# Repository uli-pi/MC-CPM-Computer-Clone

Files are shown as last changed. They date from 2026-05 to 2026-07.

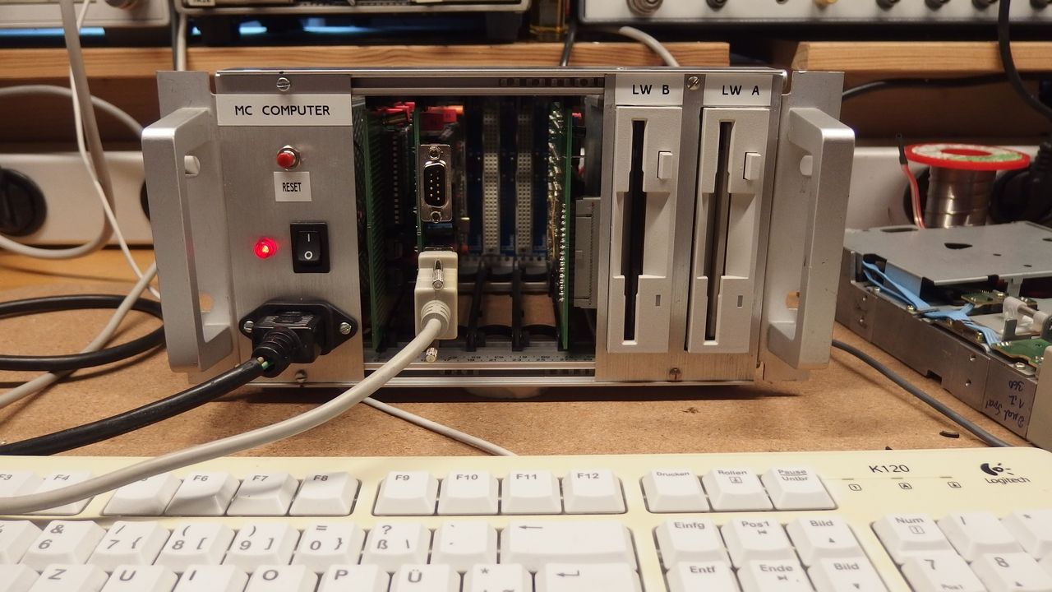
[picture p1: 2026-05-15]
MC-CLONE.jpg

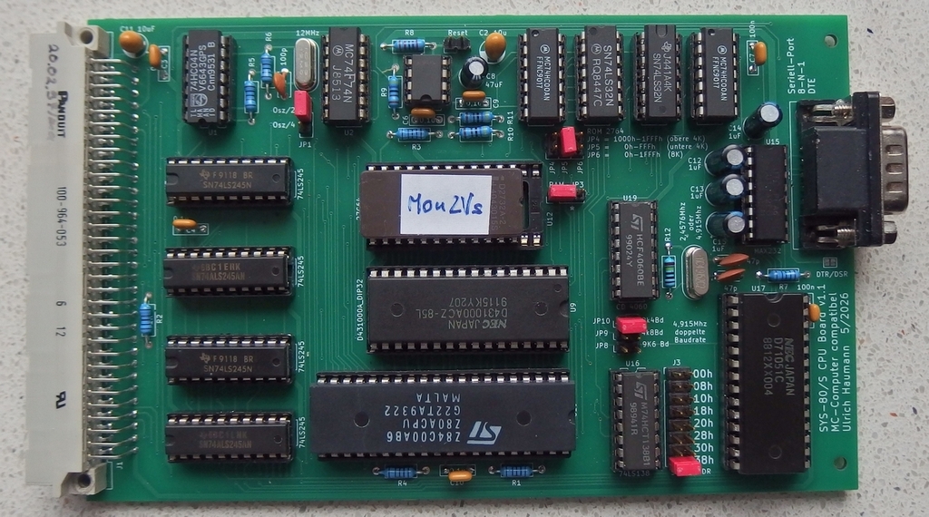
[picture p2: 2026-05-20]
SYS-80s/SYS-80s-V1.1.jpg

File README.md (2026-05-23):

# MC-Computer CP/M Computer Clone
 
Hier entsteht ein MC CP/M Computer kompatibler Rechner. Dieser wurde in der Zeitschrift MC Computer 1984 als Nachbauprojekt veröffentlicht. Der Autor war Rolf-Dieter Klein der auch den NDR Computer gleichzeitig entwickelte.
Das Projekt ist als "Retro" Computing Projekt ausgelegt. Die Karten werden nicht 1:1 "gecloned" sondern mit einigen Verbesserungen neu aufgelegt. Es wird aber alles weitgehend mit Chips aus der Zeit aufgebaut werden, also kommen keine SMD Bauteile oder Microcontroller wie Raspi, Arduino oder ähnliches zum Einsatz.

Es werden nachfolgend die Baugruppen CPU Karte (SYS-80s), OUT Karte (OUT-80), Floppy Controller (FLO-80), sowie einige neue Karten hier veröffentlicht. Die Karten sind ECB Bus Kompatibel zu eventuell vorhandenen Karten aus den 80ziger Jahren. Diese können gemischt betrieben werden. Wer also noch einen MC-CPM Computer sein eigen nennt kann z.B. Die CPU Karte gegen die neue SYS-80s tauschen usw.

Die CF Karte ermöglicht den Anschluß eines IDE Kompatiblen Gerätes. Es lassen sich Festplatten, oder auch mit Adapter eine CF Karte ansteuern. Mit dem CF Karten Bios werden 4 Floppy Disk mit jeweils 2MB Kapazität nachgebildet.

Ein minimales CP/M 2.2 System kann mit einer SYS-80s und einer CF-80 Karte aufgebaut werden. Man hat einen vollwertigen Rechner mit einem 60KB CP/M. Oder sie nehmen eine SYS-80s mit einer FLO-80 Karte. Das ergibt einen CP/M Rechner mit richtigen Floppy Laufwerken. Anschluß von 3,5", 5,25" oder 8" ist möglich, auch gemischt je nach Bios.

Mit einer OUT-80 Karte bekommt man zusätzlich 2 serielle und 2 parallele Schnittstellen.

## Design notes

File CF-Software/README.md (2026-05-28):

# CF-80 Karte - CP/M Install Anleitung für eine CF Speicherkarte

CF-Menue

Die Karte wurde für das MC-Computer ECB Bus System entwickelt und verwendet nur 8 Bit des angeschlossenen 16Bit Mediums. Das halbiert schon einmal vorweg die nutzbare Kapazität. Es sollte ein Datenträger mit mindestens 128MB verwendet werden.
Es kann auch eine ATA  oder eine SSD Festplatte verwendet werden. Das Format Programm erstellt 4 Laufwerke (LW A bis D) mit jeweils 2MB Speicherkapazität.
 
Anschluss eines Laufwerks:

Diese Karte funktioniert mit den meisten IDE/CF/SSD-Laufwerken. Die Kapazität des Laufwerks sollte 128 Megabyte oder mehr betragen, wenn Sie CP/M installieren möchten. Dies ist nicht erforderlich, um genügend Speicherplatz zu haben – denn ein vollwertiges CP/M-System belegt unter 1 MB an Speicherplatz –, sondern vielmehr weil die von mir verwendeten Treiber vereinfachten Code verwenden, der den Speicherplatz nicht sehr effizient nutzt. Es kommt eine vereinfachte Arithmetik zum Einsatz, um die CP/M-Sektoren auf die LBA-Sektoren der Festplatte abzubilden. Dabei bleibt ein erheblicher Teil des Speicherplatzes ungenutzt.  Es kann aber jeder einen Treiber selbst für das System schreiben um den Speicherplatz auszunutzen. 
Viele kleine Solid-State-Flash-Module benötigen keinen separaten Stromanschluss; stattdessen können Sie die +5V-Spannung (bei geringer Stromaufnahme) direkt über Pin 20 des Laufwerksanschlusses beziehen. Bei der vorliegenden Karte liegt dieser auf +5V und die SSD bzw. CF Karten benötigen daher keine externe Spannungsversorgung.

Die Adressen sind auf der Karte zwischen 010h bis 078h einstellbar, es werden 8 Adressen benutzt.
Für das SYS-80 System liegt die Basis Adresse auf 018Hex.

Adressen IDE Port CF-80 Karte

	IDEDATA	EQU 0x8h			;IDE Daten Register
	SECCND	EQU 0xah			;Sector Count Register
	LBA7	EQU 0xbh			;LBA Bits 0-7
	LBA15	EQU 0xch			;LBA Bits 8-15
	LBA23	EQU 0xdh			;LBA Bits 16-23
	IDEHEAD	EQU 0xeh			;IDE Drive Head Register
	IDESTAT	EQU 0xfh			;IDE Command/Status Register

Wie bekommt man nun CPM auf den Datenträger ?
Voraussetzung ist die MC-Computer SYS-80  Systemkarte mit Monitor Eprom  für den IDE-80 CF-Adapter.
Zum Erstellen einer CP/M bootfähigen CF-Karte bedienen wir uns des Monitor der SYS-80 Karte. Dieser beinhaltet viele Kommandos die zum Aufsetzen und testen eines Systems hilfreich sind.
Folgende Monitor Kommandos werden benötigt:

R offset	lädt ein INTEL HEX File über die Terminal Schnittstelle in das RAM

G offset	springt an die angegebene Adresse und  startet das Programm

Alle Monitorbefehle sind im original SYS-1 Handbuch zu finden.

Wir brauchen ein Terminalprogramm das Binärfiles über die Serielle Schnittstelle zur Console  senden kann. Ich benutze dazu RealTerm.
Die Speicheraufteilung des MC-Systems ist wie folgt:

F000 Hex ab dieser Adresse beginnt der Monitorbereich bis FFFF Hex

EA00 HEX ist die Ladeadresse des BIOS

D400 HEX ist die Ladeadresse des CCP/BDOS
	 
Daraus geht hervor wohin wir die Binärfiles laden müssen.
 
Nachfolgende Binärfiles im INTEL HEX Format werden benötigt. Sie befinden sich mit den Sourcen im CF-Software Verzeichnis.

CBIOS-CF.HEX		das angepasste Bios für die CF-Karte (Adresse EA00h)

CPM22.HEX			CCP und BDOS, original von DR (Adresse D400h)

FORM-CF.HEX		Formatiert 4 Laufwerke (Adresse 8000h)

PUTSY-CF.HEX		Kopiert CP/M auf Systemspuren (Adresse 8000h)

BLOAD-CF.HEX		Bootloader (Adresse 8000h)

BOOT-CF.HEX		Schreibt Bootloader auf LBA0 (Adresse 100h)

System Starten, Monitor meldet sich mit  > Prompt.

Um das System in einen definierten Ausganszustand zu bringen leert man zuerst den  Speicher mit folgendem Monitor Befehl  f0,ef00,0  ->Enter. 

Es muss der Datenträger für das CPM vorbereitet (formatiert) werden. Dazu nutzten wir das CPM Bios das auf den Datenträger soll. Es beinhaltet alle Funktionen die zum Schreiben von Sektoren im richtigen Format nötig sind.

Der Monitor kann nur Dateien im INTEL HEX Format empfangen!

Im Monitor eingeben rea00  -> Enter, der Monitor erwartet jetzt eine Datei die er auf Adresse EA00 Hex abspeichert.

Nun wird in Real Term mit der Send Funktion die Datei CBIOS-CF.Hex übertragen. Ist die Übertragung korrekt erfolgt meldet sich der Monitor mit FF* wieder zurück.

Nach der gleichen Methode  wird nun FORM-CF.HEX auf Adresse 8000h geladen (r8000 -> Enter).

Dann startet man das Formatprogramm mit g8000 -> Enter

Jetzt sollte das Formatprogramm arbeiten. Es werden 4 Laufwerke formatiert und die „Disk Aktiv“ LED auf der Karte leuchtet.
Das Programm  zeigt den Formatierungsfortschritt an. Geduld, das dauert ein paar Minuten. Das Programm springt, wenn fertig, wieder in den Monitor zurück.
Wenn der  Datenträger formatiert ist kann CP/M aufgespielt werden.

Die erste Datei ist CPM22.HEX, Diese kommt auf Adresse D400h. Das geht wieder  mit dem R Kommando:  rd400 -> Enter. Diese originale DR Datei enthält das CCP, BDOS und eine leere Sprungtabelle für CP/M 2.2. Datei in Real Term auswählen und übertragen.

Dann patchen wir das BIOS in das leere CP/M. Dies ist die Datei CBIOS-CF.HEX, kommt auf Adresse EA00h. Wie gehabt mit dem R Befehl (rea00 -> Enter).

Das komplette CP/M ist nun im Ram und muss auf den Datenträger geschrieben werden.
Dazu lädt man nun PUTSY-CF.HEX auf Adresse 8000h 

Mit einem G Befehl auf Adresse 8000h (g8000 -> Enter) wird das Programm gestartet und schreibt CP/M auf den Datenträger. Nun sollte die LED auf der CF-80 Karte kurz aufleuchten.

Im Übrigen ist CP/M jetzt betriebsbereit wir haben nur noch keinen Kalt Start (BOOT).
Geben Sie gea00 -> ein und CP/M wird sich melden.

Zum Weitermachen wieder in den Monitor mit dem Reset Knopf.

Jetzt fehlt nur noch der „Cold Boot Loader“ um CP/M bei einem Kaltstart ins Ram zu schreiben und zu starten.
Dazu wird BLOAD-CF.HEX auf Adresse 8000h geladen.

Danach wird BOOT-CF.HEX auf Adresse 100h geladen (r100 )und mit g100 gestartet.

Reset Knopf drücken. Nun wird mit dem Monitor Befehl  I  das Bootmenue aufgerufen und mit Auswahl =2 die CF Karte ausgewählt. Das CP/M sollte starten.

Wir haben ein CP/M mit 4 Laufwerken (A bis D) und keine Dateien auf dem Datenträger. Das macht keinen Spaß, wir brauchen Programme.

Dazu benutzen wir erst einmal wieder unsere Lademethode mit Monitor und RealTerm. Reset drücken, wir brauchen den Monitor.

Die Datei der Begierde ist GETPC.COM , damit lassen sich alle Dateien über XMODEM auf unser CP/M laden.
Mit r100h, GETPC.HEX ins RAM laden. 

Nun wird mit dem Monitor Befehl  I  das Bootmenue aufgerufen und mit Auswahl =2 die CF Karte ausgewählt. Das CP/M sollte starten. 
Das GETPC ist immer noch unversehrt im RAM.

Das erste Kommando in CP/M ist nun save 5 getpc.com und wir haben das Programm auf dem Datenträger. Somit lassen sich beliebige Programme auf den Datenträger überspielen was aber ziemlich mühsam wäre. Aber wir haben jetzt GETPC.

Wir wechseln das Terminal Programm und verwenden ab sofort TerraTerm. Dieses Programm hat ein integriertes XMODEM.

Auf auf dem CP/M Rechner rufen wir GETPC Filename.ext auf. Filename.ext entspricht der Datei die wir übertragen wollen. Dann wartet CP/M auf das File. Der Filename ist frei wählbar das Programm überträgt einfach die Datei und speichert sie unter dem gewählten Namen ab.

Auf dem PC im Programm TerraTerm sind es die Kommandos DATEI, TRANSFER, XMODEM, SEND und Datei auswählen. Wir brauchen uns über Länge und Speicherplatz nicht mehr zu kümmern. Das machen die Programme untereinander aus.

Zurückspielen von CP/M auf PC geht dann mit PCPUT.com das wir ja jetzt mit GETPC  einfach auf unseren CP/M Rechner holen können.
GETPC.com und PUTPC.com sind Kopien von PCGET.com und PCPUT.com die auf die Hardware der SYS80s Karte angepasst wurden. Ich habe diese umbenannt damit man nicht mit den Varianten für das originale System mit OUT Karte durcheinander kommt. Da die Programme direkt über die Hardware kommunizieren, müssen sie immer an die verwendete Hardware angepasst werden.

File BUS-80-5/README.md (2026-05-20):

# 5-Slot-Backplane

Backplane mit 5 Slots zur direkten Montage in Baugruppenträger oder in das unten verlinkte Gehäuse ohne Z-Schiene.

BUS-80-5

JLCPCB-geprüfte Gerber-Files im Verzeichnise /gerber

Achtung - Dies ist eine Kopie des 8-Slot-Busboards, wobei im Layout-Editor 3 Slot entfernt wurden ohne den Schaltplan anzupassen.

Passendes Gehäuse bei Reichelt Elektronik: https://www.reichelt.de/de/de/shop/produkt/systemgehaeuse-50437

Erstellt mit KiCAD 9.07 / Detlef Gerhardt

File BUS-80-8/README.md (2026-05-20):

# 8-Slot-Backplane

Backplane mit 8 Slots zur direkten Montage in Baugruppenträger oder in das unten verlinkte Gehäuse ohne Z-Schiene.

BUS-80-8

Passendes Gehäuse bei Reichelt Elektronik: https://www.reichelt.de/de/de/shop/produkt/systemgehaeuse-50437

Erstellt mit KiCAD 9.07 / Detlef Gerhardt

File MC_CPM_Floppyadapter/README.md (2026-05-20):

# 3 1/2" Floppy-Adapter

Adapter zum Anschließen von 3 1/2" PC-Laufwerken an den Floppy-Controller des MC-CPM-Clones.
Dabei werden die 4 Drive-Select-Leitungen vom Controller in die MOTOR_ON A/B und DRIVE SELECT A/B Leitungen des Laufwerks angepasst.

Adapter1

JLCPCB-geprüfte Gerber-Files im Verzeichnise /gerber

Erstellt mit KiCAD 9.07 / Detlef Gerhardt

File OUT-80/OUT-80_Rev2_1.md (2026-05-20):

**Die „neue“ OUT-80 Karte (Rev. 2.1)**

… Ist nach wie vor voll MC-Computer kompatibel.

Die Karte ist fest auf die MC-Computer Seriell I/O Basis adr 0F0hex eingestellt. Die Adressbelegung entspricht der MC-Computer Terminologie und steht auf der Karte. Die Karte liegt mehrfach im I/O Adressraum, so auch wieder bei 1F0hex usw. Da hat man sich wenig Mühe gemacht und eine volle Dekodierung hätte auch den Rahmen gesprengt.

Die RS 232 Schnittstellen sind als DTE geschaltet wie es sich für einen Computer gehört. Das bedeutet zum PC braucht man ein gedrehtes Kabel (Nullmodem Kabel) weil auch der PC als DTE konfiguriert ist. SIO A ist der Terminal Port (TTY), SIO B war damals als Punch Kanal definiert.

An den Sub D9 Steckern sind die Signale DCD und DTR nicht aufgelegt, da die häufig nicht gebraucht werden. Wer die Signale dennoch benötigen sollte kann das auf dem kleinen Lötrasterfeld verwirklichen und einen weiteren RS232 Treiber einbauen.

Wenn man ein Kabel nur mit 3 Leitungen (RX/TX/GND) verwendet muss man die CTS/RTS Jumper auf der Platine stecken oder in der Kabelbuchse Brücken. Die Software fragt das ab. Man kann natürlich auch die Initialisierung im ROM Ändern.

Es gibt jetzt 2 LED auf der Platine. Sie sind an die Chip Select Anschlüsse der SIO und PIO angeschlossen und leuchten wenn diese selektiert werden (da waren noch 2 Gatter frei die ich dafür benutzt habe). Bitte hier 3mA LED verwenden damit die Gatter nicht so belastet werden.

Nicht wundern das die SIO LED leuchtet wenn der MC-Computer gestartet ist, es wird ja ständig der Port angesprochen um zu sehen ob ein Zeichen da ist. Bei Disk Operationen z.B. geht sie schon mal aus weil ja die SIO dann pausiert. Sieht man auch schön wenn man sich eine Datei mit „TYPE“ anschaut.

Folgendes zu den SIO Chip‘s:

Getestet habe ich mit original Z80-SIO-0 und Zilog Z84C4006. Da der MC-Monitor ROM die SIO mit komplettem Handshake initialisiert, muss man bei der Z80-SIO-0 die auf der Platine vorgesehenen Jumper auf DCD/DTR stecken. Sonst geht keine Eingabe.

Die PIO (Z80-PIO) war als Parallele Centronics Drucker Schnittstelle gedacht. Da gab es ein kleines Programm um diese zu initialisieren. Man kann die Pio natürlich für jede andere Art von Steuerungen verwenden. Sie kann auch weggelassen werden, das hat keinen Einfluss auf die Seriellen Port’s.

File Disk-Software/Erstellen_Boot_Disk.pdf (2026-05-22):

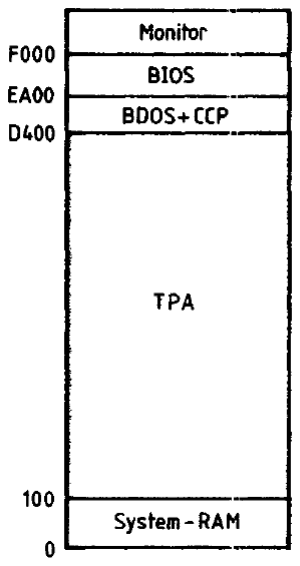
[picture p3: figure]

Erstellen einer Boot Diskette | Seite - 1 -

Erstellen einer Boot Diskette für MC-Computer

Wie bekommt man nun CPM auf den Datenträger ?

Zum Erstellen einer CP/M bootfähigen Diskette bedienen wir uns des Monitor der SYS-80 Karte. Dieser beinhaltet viele Kommandos die zum Aufsetzen und Testen eines Systems hilfreich sind.

Folgende Monitor Kommandos werden benötigt:

R offset | lädt ein INTEL HEX File über die Terminal Schnittstelle in das RAM
G offset | springt an die angegebene Adresse und startet das Programm

Wir brauchen ein Terminalprogramm das Binärfiles über die Serielle Schnittstelle zur Console senden kann. Ich benutze dazu RealTerm.

Die Speicheraufteilung des MC-Systems ist wie folgt:

Daraus geht hervor wohin wir die Binärfiles laden müssen.

Folgende Binärfiles im INTEL HEX Format werden benötigt:

BIOS80.HEX | angepasstes Bios (Adresse EA00h)

Das Bios enthält die Definitionen für 4 Laufwerke 2 x 80 Spur NDR Format (A und B) sowie 2 x 8“ IBM Format (C und D)

CPM22.HEX | CCP und BDOS, original von DR (Adresse D400h)
UFORMAT.HEX | Universal Format Programm (Adresse 100h)
PUTSYS80.HEX | Schreibt CP/M auf Systemspuren (Adresse 100h)
LOAD80.HEX | Schreibt Bootloader auf Disk (Adresse 100h)
BOOT80.HEX | Bootloader (Adresse 1000h)

System Starten, Monitor meldet sich mit > Prompt.

Um das System in einen definierten Ausganszustand zu bringen leert man zuerst den Speicher mit folgendem Monitor Befehl f0,ef00,0 -> Enter. Damit leert man den Speicher bis zum Monitor Bereich.

Es muss der Datenträger für das CPM vorbereitet (formatiert) werden. Dazu nutzten wir die Datei UFORMAT.HEX . Dies ist ein universal Formatier Programm für den MC-CP/M Computer.

Der Monitor kann nur Dateien im INTEL HEX Format empfangen!

Nun wird im Terminal Programm (Real Term), über die Konsol Schnittstelle, mit der Send Funktion die Datei UFORMAT.Hex übertragen.

Dazu gibt man im Monitor r100 -> Enter ein. Der Monitor erwartet jetzt eine Datei die er auf Adresse 100 Hex abspeichert. Jetzt muss das Programm UFORMAT.HEX mit der Send Funktion des Terminal Programm übertragen werden. Ist die Übertragung korrekt erfolgt meldet sich der Monitor mit FF* wieder zurück. Dann startet man das Formatprogramm mit g100 -> Enter

Im Format Programm wählt man den Menü Punkt (5) NDR Format. Dies funktioniert für 3,5“ und 5,25“ Disketten gleichermaßen je nachdem welche Hardware angeschlossen ist. Bei 3,5“ Disketten muss das „HD-Loch“ abgeklebt werden.

FLO2 Auswählen (1),Laufwerk A (1), dann mit ja (J) bestätigen.

Wenn der Datenträger formatiert ist kann CP/M aufgespielt werden.

Dazu muss der Monitor wieder mit der Reset Taste gestartet werden.

Die erste Datei ist CPM22.HEX, Diese kommt auf Adresse D400h. Das geht wieder mit dem R Kommando: rd400 -> Enter. Diese originale DR Datei enthält das CCP, BDOS und eine leere Sprungtabelle für CP/M 2.2. Datei in Real Term auswählen und übertragen.

Dann patchen wir das BIOS in das leere CP/M. Dies ist die Datei BIOS80.HEX, kommt auf Adresse EA00h. Wie gehabt mit dem R Befehl. (rea00h)

Das komplette CP/M ist nun im Ram und muss auf den Datenträger geschrieben werden.

Dazu lädt man nun PUTSYS80.HEX auf Adresse 100h (r100). Mit g100 wird das Programm gestartet und schreibt das System auf die Diskette.

Jetzt meldet sich CP/M zum ersten mal. Wir haben aber noch keinen Boot Loader auf der Diskette. Also Reset Taste drücken und zurück in den Monitor.

Man lädt nun den Bootloader BOOT80.HEX auf Adresse 1000h und das Programm LOAD80.HEX auf Adresse 100h (r100). Mit g100 wird der Loader nun gestartet. Dieser schreibt den Boot Sektor auf die Diskette.

Jetzt meldet sich CP/M wieder. Die Boot Diskette ist fertig.

Reset Knopf drücken.

Mit dem Monitor Befehl I wird das Bootmenue aufgerufen und mit Auswahl =1 der FLO2 Boot ausgewählt. Die Diskette sollte booten. Ab jetzt ist es möglich mit dem Programm Sysgen80.com das System auf andere NDR 80 formatierte Disketten zu übertragen.

Wir haben ein CP/M mit 4 Laufwerken (A bis D) und keine Dateien auf dem Datenträger. Das macht keinen Spaß, wir brauchen Programme.

Dazu benutzen wir erst einmal wieder unsere Lademethode mit Monitor und RealTerm. Reset drücken, wir brauchen den Monitor.

Die nun wichtige Datei ist GETPC.COM , damit lassen sich alle Dateien über XMODEM auf die Diskette laden.

Mit r100h, GETPC.HEX ins RAM laden.

Da der Bootloader den TPA zerstören würde in dem jetzt GETPC steht startet man das CP/M direkt mit dem Monitor Befehl gea00.

CP/M meldet sich und das GETPC ist immer noch unversehrt im RAM.

Das erste Kommando in CP/M ist nun save 5 getpc.com und wir haben das Programm auf dem Datenträger. Somit lassen sich beliebige Programme auf den Datenträger überspielen was aber ziemlich mühsam wäre. Aber wir haben jetzt GETPC.COM. GetPC verwendet zur Übertragung von Dateien das XMODEM Protokoll. Wir wechseln das Terminal Programm und verwenden ab sofort TerraTerm. Dieses Programm hat ein integriertes XMODEM.

Auf der CP/M Seite rufen wir GETPC Filename.ext der Datei die wir übertragen wollen auf. Dann wartet CP/M auf das File. Der Filename ist frei wählbar das Programm überträgt einfach die Datei und speichert sie unter dem gewählten Namen ab.

Auf dem PC im Programm TerraTerm sind es die Kommandos DATEI, TRANSFER, XMODEM, SEND und Datei auswählen. Wir brauchen uns über Länge und Speicherplatz nicht mehr zu kümmern. Das machen die Programme untereinander aus.

Zurückspielen von CP/M auf PC geht dann mit PCPUT.com das wir ja jetzt mit GETPC einfach auf unseren CP/M Rechner holen können.

GETPC.com und PUTPC.com sind Kopien von PCGET.com und PCPUT.com die auf die Hardware der SYS80s Karte angepasst wurden. Ich habe diese umbenannt damit man nicht mit den Varianten für das originale System mit OUT Karte durcheinander kommt. Da die Programme direkt über die Hardware kommunizieren müssen sie immer an die verwendete Hardware angepasst werden.

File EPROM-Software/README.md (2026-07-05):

# Monitor Eprom Dateien für SYS-80s:

Mon80V1.bin - Monitor für SYS-80s mit CF-Boot und "onboard" RS-232 Schnittstelle auf Adresse 20Hex

Der Monitor ist 4KB groß und passt auch in ein 2732 Eprom.

Der Monitor wird akuell gerade überarbeitet und dokumentiert (Mon80V2). Im ersten Schritt ändert sich nur der Quelltext und der Monitor bleibt binärkompatibel.
Im zweiten Schritt sollen dann unnötige Sprünge und nicht mehr benötigte Routinen entfernt werden. Über IF/ENDIF sollen dann verschiedene Konfigurationen erstellt werden können. Zum Beispiel für unterschiedliche Schnittstellenkonfigurationen.

Mon80V1 ist die Original-Version des Monitors

Mon80V2 ist binaer identisch, aber der Quelltext wurde stark überarbeitet und kommentiert.
Mon80V2 wird die Basis für einen zukünftig überarbeiteten Monitor sein.

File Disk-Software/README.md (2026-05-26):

# DISK Software für SYS-80s

Eines der größten Probleme bei einem neu gebauten System ist: Wie bekomme ich ein Boot fähiges Medium um CP/M zu starten? In diesem Verzeichnis befinden sich alle Dateien um eine Boot Diskette im NDR 80Spur Format zu erstellen. 

Das verwendete BIOS ist Hardwareseitig für den MC-CP/M Computer programmiert.
Für Disketten brauchen Sie natürlich eine Floppy Karte FLO-80 bzw. original FLO2 und ein entsprechendes Laufwerk. 3,5", 5,25" oder auch 8" Laufwerke sind möglich.
Bei Verwendung von 3,5" Disketten ist das "HD-Loch" abzukleben. Oder Sie verwenden eine Compact Flash Karte. Anleitung dazu siehe CF-Karte.

Im diesem Bios sind 2 Laufwerke (A,B) im NDR Format (80TRK, 5 x 1024, 800KB) und 2 Laufwerke (C,D) im 8"  im IBM Format definiert. 3,5" Laufwerke verhalten sich wie 8" Laufwerke. Eine 3,5" Diskette mit offenen HD Loch kann als IBM 8" Diskette formatiert werden. 

Für das NDR 80TRK Format können 3,5" oder auch 5,25" Laufwerke verwendet werden. Das Bios ist für beide Laufwerksarten identisch. Bei Verwendung von 3,5" Disketten ist das "HD-Loch" auf der Disk abzukleben. Bei Verwendung von 5,25" Laufwerken müssen Sie darauf achten das, das Laufwerk als Double Density (DD) konfiguriert ist. PC Laufwerke in der Standard Einstellung arbeiten im HD Modus und funktionieren mit diesem Bios nicht. Die meisten 5,25" Laufwerke kann man auf DD umstellen. Anleitungen dazu findet man im Internet. Das würde hier den Rahmen sprengen, da ist jedes Laufwerk anders.  

Wenn man ein CP/M System mit richtigem Floppy Laufwerk aufbauen möchte ist der einfachste Weg die Benutzung eines 3,5" Laufwerkes. Der in diesem Projekt  beschriebene Floppy Adapter ermöglicht es die 3,5" Laufwerke an die FLO-80 anzuschließen und die Laufwerk ID einzustellen.

Das Erstellen einer BOOT Diskette ist im PDF "Erstellen-Boot-Disk" beschrieben.

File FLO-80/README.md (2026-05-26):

# Floppy Controller FLO-80

FLO-80

Die Flo-80 Karte ist kompatibel zur FLO-2 Karte des MC CP/M Computers. 
Es wurde der FDC9239BT Datenseparator benutzt da die alte originale FLO-Karte erhebliche Probleme mit dem Datenseparator hatte. In der ersten FLO Karte war der Datenseparator noch diskret aufgebaut und ohne Oszilloskope war ein Abgleich nur schwer möglich. Dann gab es eine Umbauanleitung mit dem 9216 Datenseparator. Die folgenden FLO Karten verwendeten den FDC 9229 Chip.
 
Auf den FLO-80 Karten können FDC9239BT oder FDC9229BT bestückt werden, je nachdem welcher Chip erhältlich ist. Dies ist mit 2 Jumpern einstellbar.
 
Für den FDC9229BT ist zwingend der Quarzoszillator X1 erforderlich. Beim FDC9239BT kann anstelle des X1 auch der Quarz Y1 eingesetzt werden.

Es sind Pfostenstecker für 3,5" bzw.  5,25" und 8" Laufwerke vorhanden. Die Dekodierung erlaubt den direkten Anschluss von 4 Laufwerken. Modere PC Laufwerke haben meist  keinen "READY" Anschluss mehr, da der PC heute stattdessen den Disk Change Anschluss benutzt. Manche Laufwerke können mittels Jumper auf die Signale eingestellt werden. Bei dem größten Teil der Laufwerke ist dies aber nicht oder nur mit Eingriff in die Elektronik möglich. Der Floppy Controller Chip benötigt aber dieses Signal, daher kann die FLO-80 Karte Ihr eigenes Ready Signal erzeugen. Hierzu sind die Jumper DS1 bis DS4 Vorgesehen. Somit können alle Laufwerke verwendet werden.
Mittels Adapter ist es möglich 3,5" Laufwerke anzuschließen.  Man benötigt ein 1:1 Kabel. Bei einem gedrehten PC Floppy Anschlusskabel muss man den Stecker für das zweite Laufwerk von dem gedrehten Teil auf den geraden Teil umklemmen. Auf dem Adapter ist die ID für Disk 1 bis 4 (entspricht Laufwerk A bis D) per Jumper einstellbar.

3,5" Disk Laufwerke sind heute noch gut zu bekommen und lassen sich im MC-Computer nutzen.
Wird bei  3,5" Disketten das HD "Loch" zugeklebt, sind die Disketten als DD Disketten nutzbar. Diese können dann mit NDR Format formatiert und als 800KB Disketten genutzt werden. 
Es gilt weiterhin die originale Beschreibung der FLO2 Karte.

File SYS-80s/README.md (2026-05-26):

# SYS-80s CPU Karte

SYS-80s-V1 1

MC CP/M Computer kompatible CPU Karte zur originalen MC-Computer SYS-1 Karte.

Die SYS-80s Karte hat eine serielle Schnittstelle on Board und benötigt daher zum Betrieb keine  OUT-Karte wie ursprünglich im MC-CP/M Computer vorgesehen. Das Consol Terminal wird direkt an die CPU Karte angeschlossen. Die Einheit kann "Standalone" als vollwertiger Z80 Rechner betrieben werden.

Es gibt ein angepasstes Monitor Eprom (Mon80V1.bin) um diese Schnittstelle als Console zu nutzen. Die SYS-80s kann auch mit dem originalen Monitor Eprom benutzt werden dann ist die Console zur OUT Karte umgeleitet und die "on Board" Schnittstelle frei.

Es ist somit möglich die SYS-80s CPU Karte als 1:1 Ersatz für eine alte SYS-1 zu verwenden wenn diese defekt sein sollte.

Auf der SYS-80 Karte wird ein statisches 128KB RAM verwendet. Der Z80 kann aber nur 64KB adressieren so bleibt die Hälfte des RAM ungenutzt. Der Chip war deutlich preiswerter als andere Lösungen daher wurde er verwendet. Vielleicht ergibt sich ja in Zukunft die Möglichkeit mit einem Hardware "banking" die zweiten 64KB nutzbar zu machen. Der EPROM Sockel erlaubt 4KB oder 8KB Eproms zu benutzen, dies ist per Jumper einstellbar.

Der CPU Takt ist mit einem 12Mhz Quarz zwischen 6Mhz und 3Mhz umschaltbar. Bei Benutzung von 8" Floppy Laufwerken ist 6Mhz erforderlich. Heute gibt es genug Z80 Varianten die schnellen CPU-Takt vertragen.

Der Schnittstellen Chip (D71051C)ist eine schnelle Variante des 8251. Der Chip ist Hard und Software kompatibel. Es lässt sich deshalb auch ein 8251 einsetzen. Während der 8251 bei  Taktraten jenseits 4Mhz Probleme bereitet kann der 71051 bis über 8Mhz getaktet werden.
Die Standard Adresse der seriellen Schnittstelle für das Monitor Eprom (Mon80V1.bin) liegt bei 20H. Per Jumper einstellbar. Mit einem UART Quarz von 4,915 Mhz lässt sich die Übertragung der seriellen Schnittstelle mittels Jumper auf 19,2K Baud, 9,6K Baud und 4,8K Baud einstellen. Mit 2,45Mhz Quarz halbieren sich die Baudraten.

Es gilt weiter die originale Beschreibung der SYS-1 Karte. In dem "Mon80V1" Eprom sind alle Monitor Befehle aus der SYS-1 Beschreibung implementiert. Zusätzlich gibt es 2 Routinen zum lesen und schreiben auf die IDE/CF Schnittstelle für CF Karten. Diese können aber nur aus Programmen über "Call" angesprochen werden.

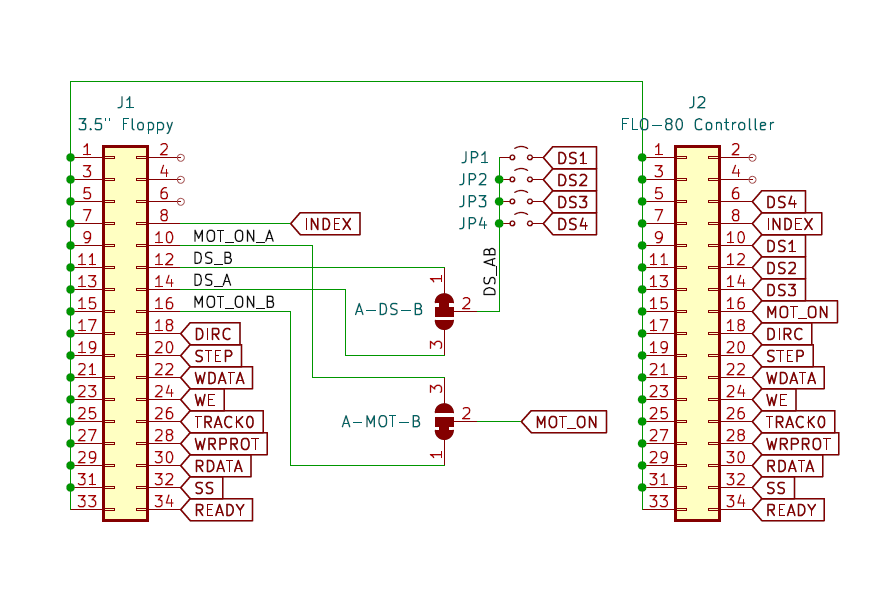
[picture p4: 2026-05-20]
MC_CPM_Floppyadapter/Adapter1.png

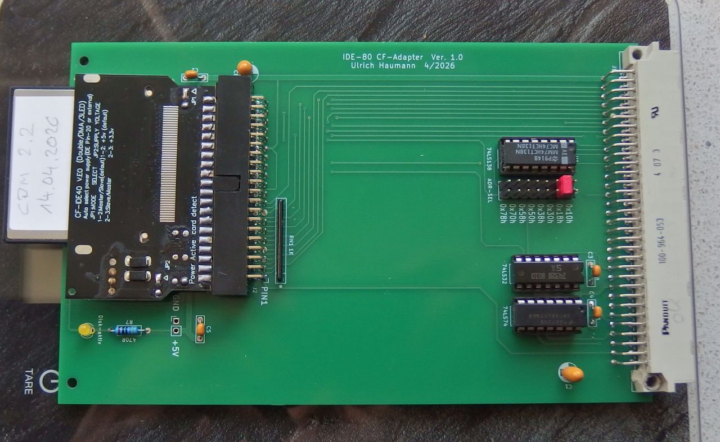
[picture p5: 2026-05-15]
CF-80/CF-80.jpg

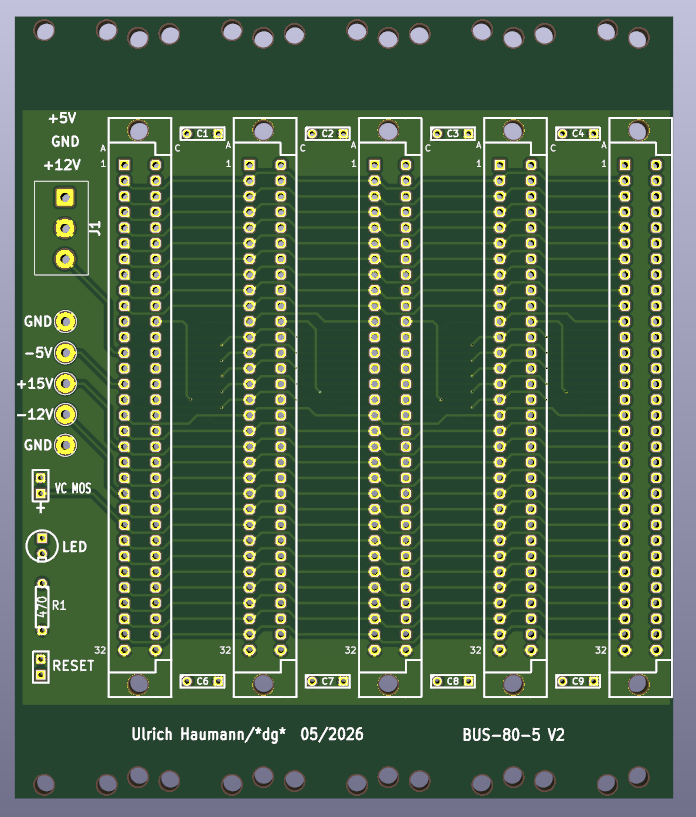
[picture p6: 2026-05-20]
BUS-80-5/BUS-80-5.png

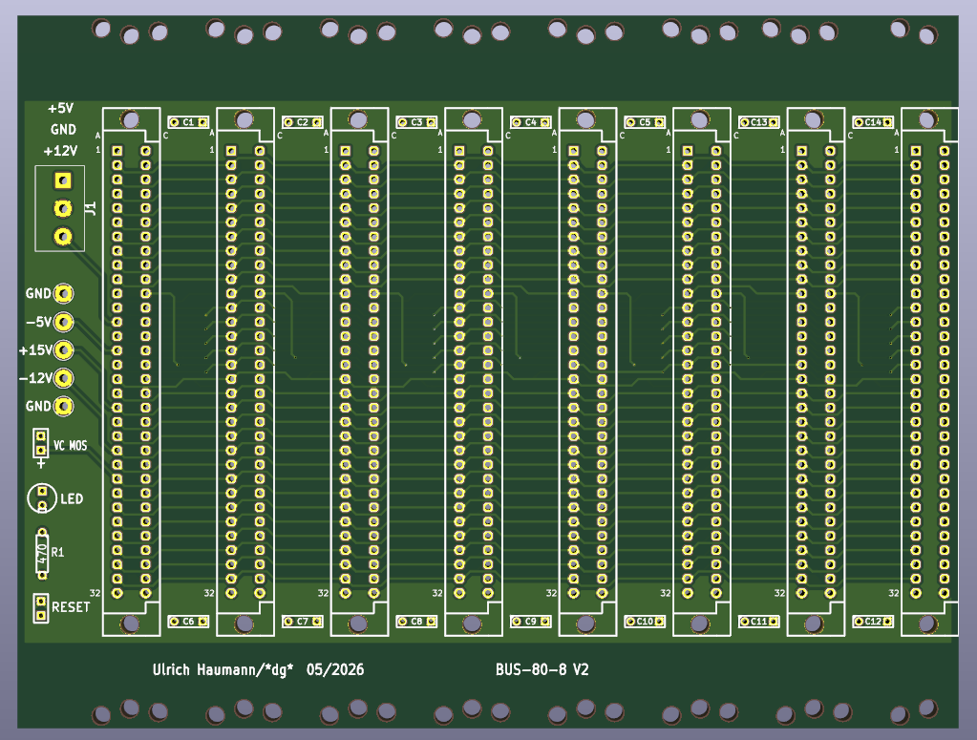
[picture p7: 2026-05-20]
BUS-80-8/BUS-80-8.png

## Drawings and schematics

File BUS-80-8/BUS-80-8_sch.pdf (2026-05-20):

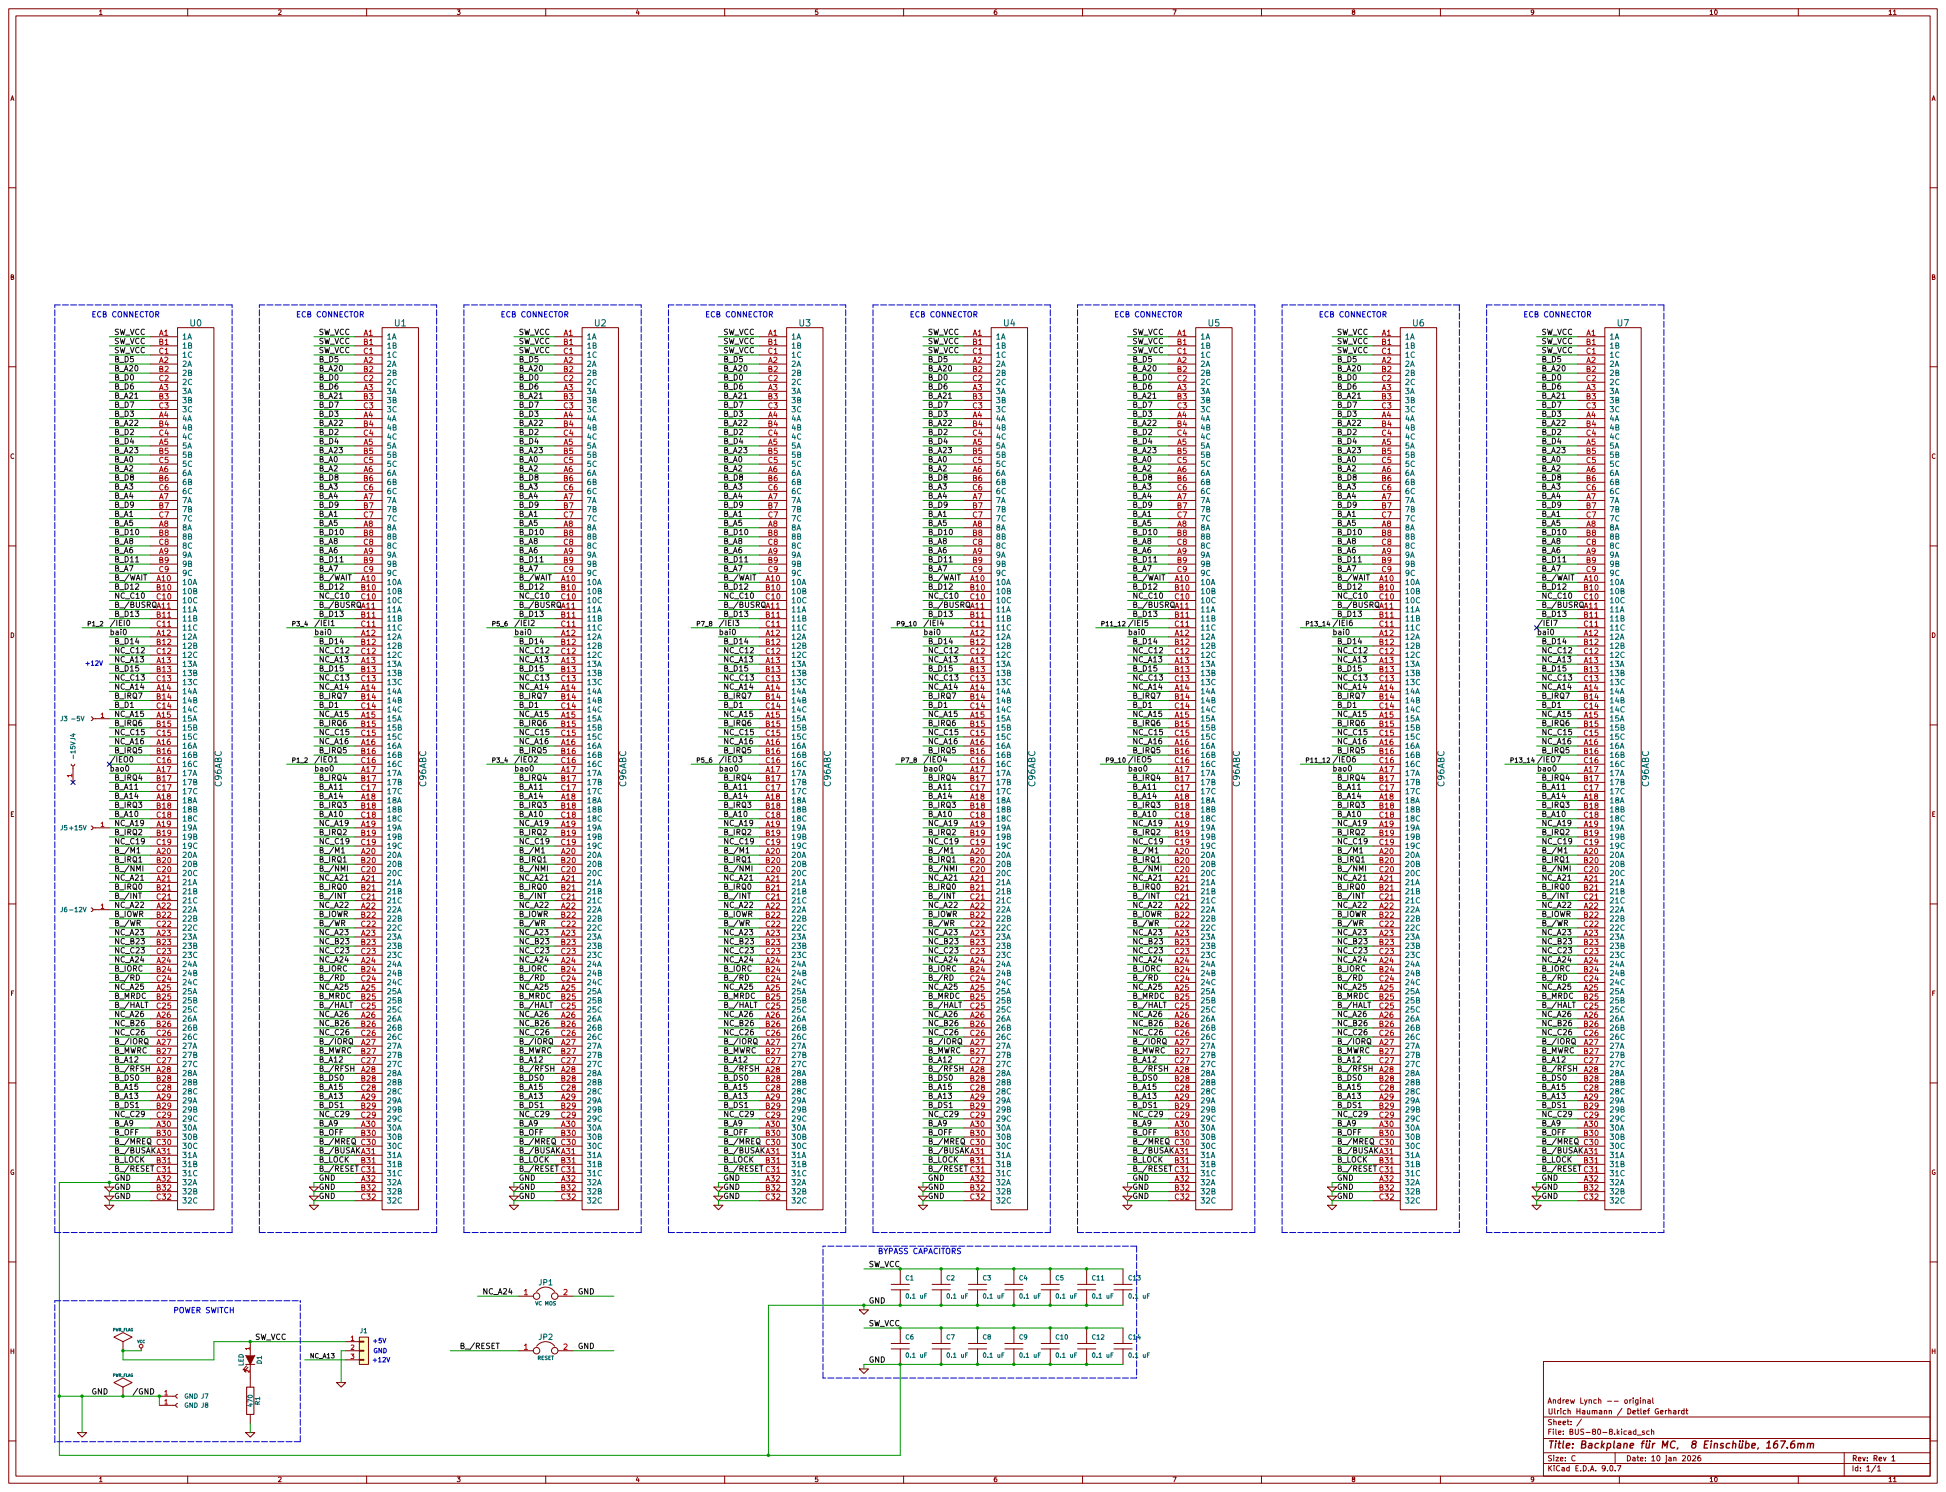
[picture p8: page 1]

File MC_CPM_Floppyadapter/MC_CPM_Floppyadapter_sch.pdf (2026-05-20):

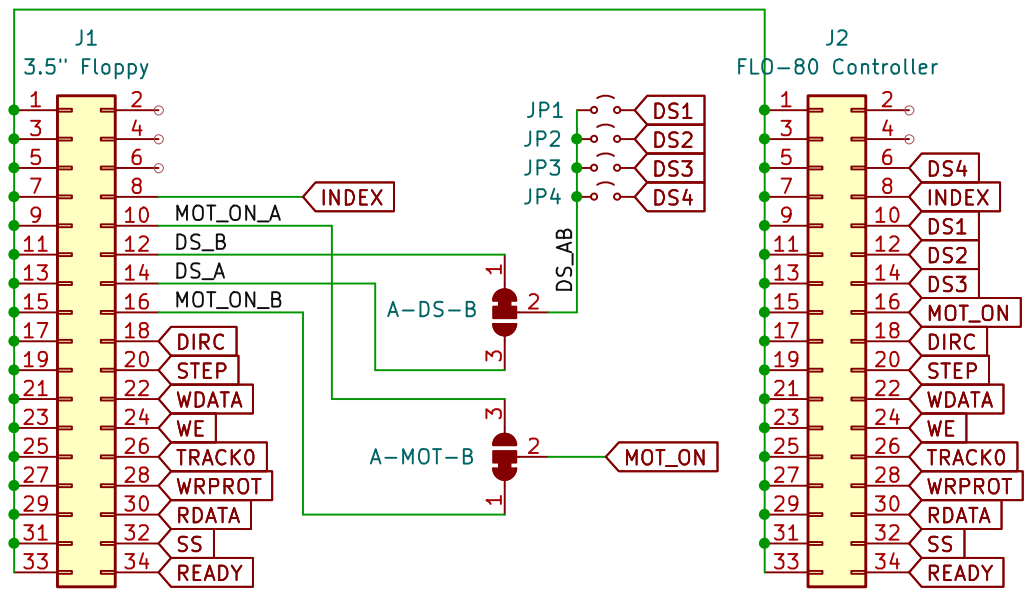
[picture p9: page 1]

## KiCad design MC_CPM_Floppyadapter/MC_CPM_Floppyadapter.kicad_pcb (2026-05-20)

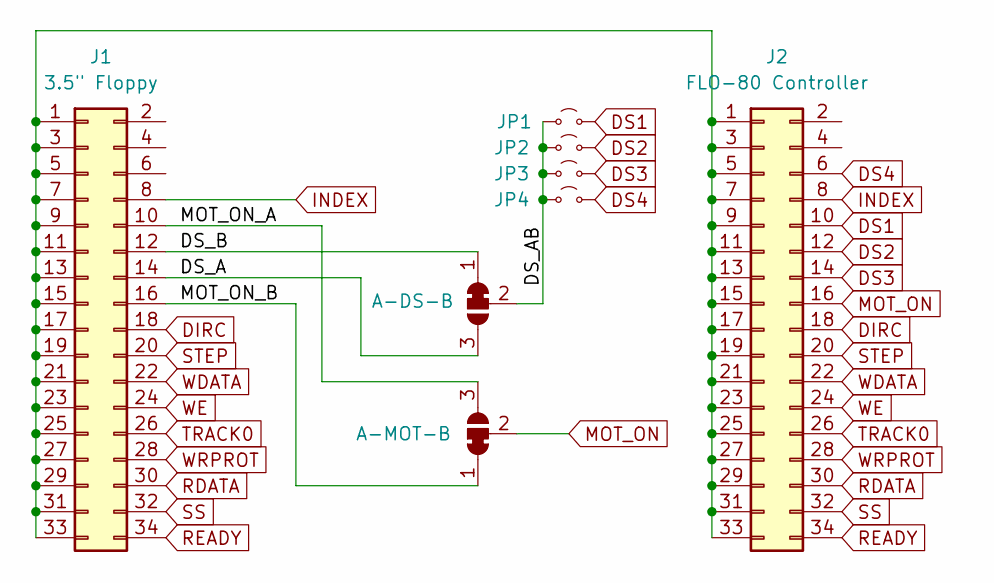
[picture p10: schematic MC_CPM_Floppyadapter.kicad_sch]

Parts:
J1: 3.5" Floppy; PinSocket_2x17_P2.54mm_Vertical
J2: FLO-80 Controller; PinHeader_2x17_P2.54mm_Vertical
JP1: DS1; PinHeader_1x02_P2.54mm_Vertical
JP2: DS2; PinHeader_1x02_P2.54mm_Vertical
JP3: DS3; PinHeader_1x02_P2.54mm_Vertical
JP4: DS4; PinHeader_1x02_P2.54mm_Vertical
JP5: A-DS-B; SolderJumper-3_P1.3mm_Bridged2Bar12_RoundedPad1.0x1.5mm
JP6: A-MOT-B; SolderJumper-3_P1.3mm_Bridged2Bar12_RoundedPad1.0x1.5mm

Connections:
/DS_A: J1.14, JP5.3 (B)
/DS_AB: JP1.1 (A), JP2.1 (A), JP3.1 (A), JP4.1 (A), JP5.2 (C)
/DS_B: J1.12, JP5.1 (A)
/MOT_ON_A: J1.10, JP6.3 (B)
/MOT_ON_B: J1.16, JP6.1 (A)
DIRC: J1.18, J2.18
DS1: J2.10, JP1.2 (B)
DS2: J2.12, JP2.2 (B)
DS3: J2.14, JP3.2 (B)
DS4: J2.6, JP4.2 (B)
INDEX: J1.8, J2.8
MOT_ON: J2.16, JP6.2 (C)
unnamed: J1.1, J1.3, J1.5, J1.7, J1.9, J1.11, J1.13, J1.15, J1.17, J1.19, J1.21, J1.23, J1.25, J1.27, J1.29, J1.31, J1.33, J2.1, J2.3, J2.5, J2.7, J2.9, J2.11, J2.13, J2.15, J2.17, J2.19, J2.21, J2.23, J2.25, J2.27, J2.29, J2.31, J2.33
RDATA: J1.30, J2.30
READY: J1.34, J2.34
SS: J1.32, J2.32
STEP: J1.20, J2.20
TRACK0: J1.26, J2.26
WDATA: J1.22, J2.22
WE: J1.24, J2.24
WRPROT: J1.28, J2.28

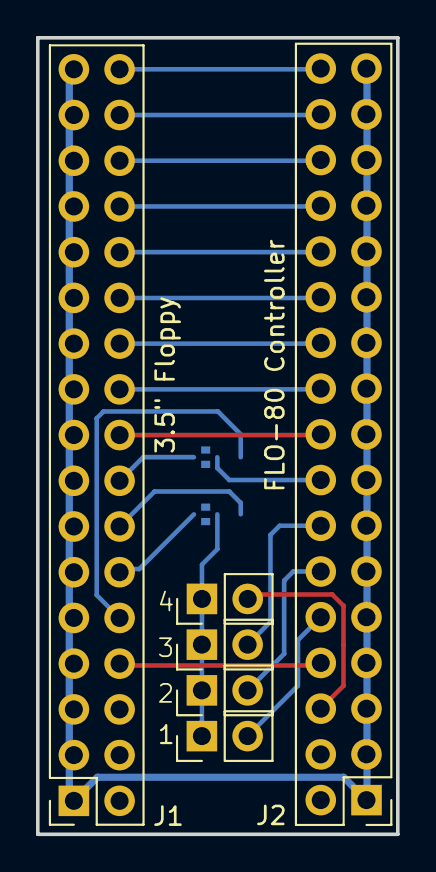
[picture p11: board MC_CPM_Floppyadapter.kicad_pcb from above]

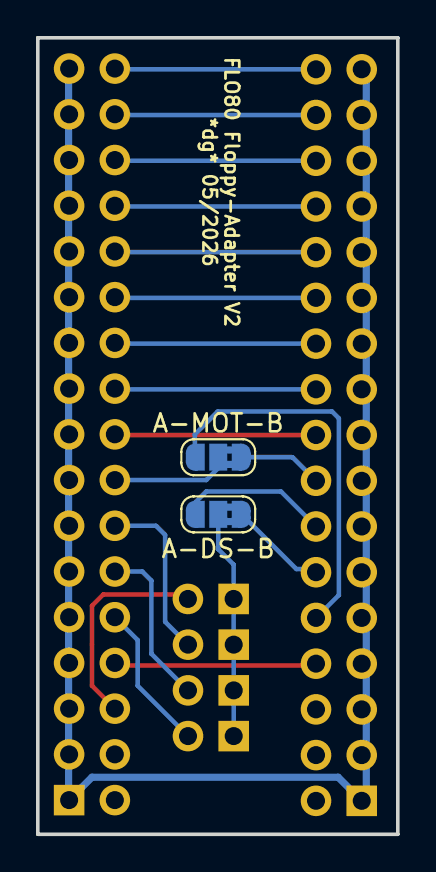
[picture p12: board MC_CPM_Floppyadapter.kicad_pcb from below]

Board: 2 copper layers, 20.0 x 44.2 mm, 8 parts (2 on the bottom side), 21 nets.

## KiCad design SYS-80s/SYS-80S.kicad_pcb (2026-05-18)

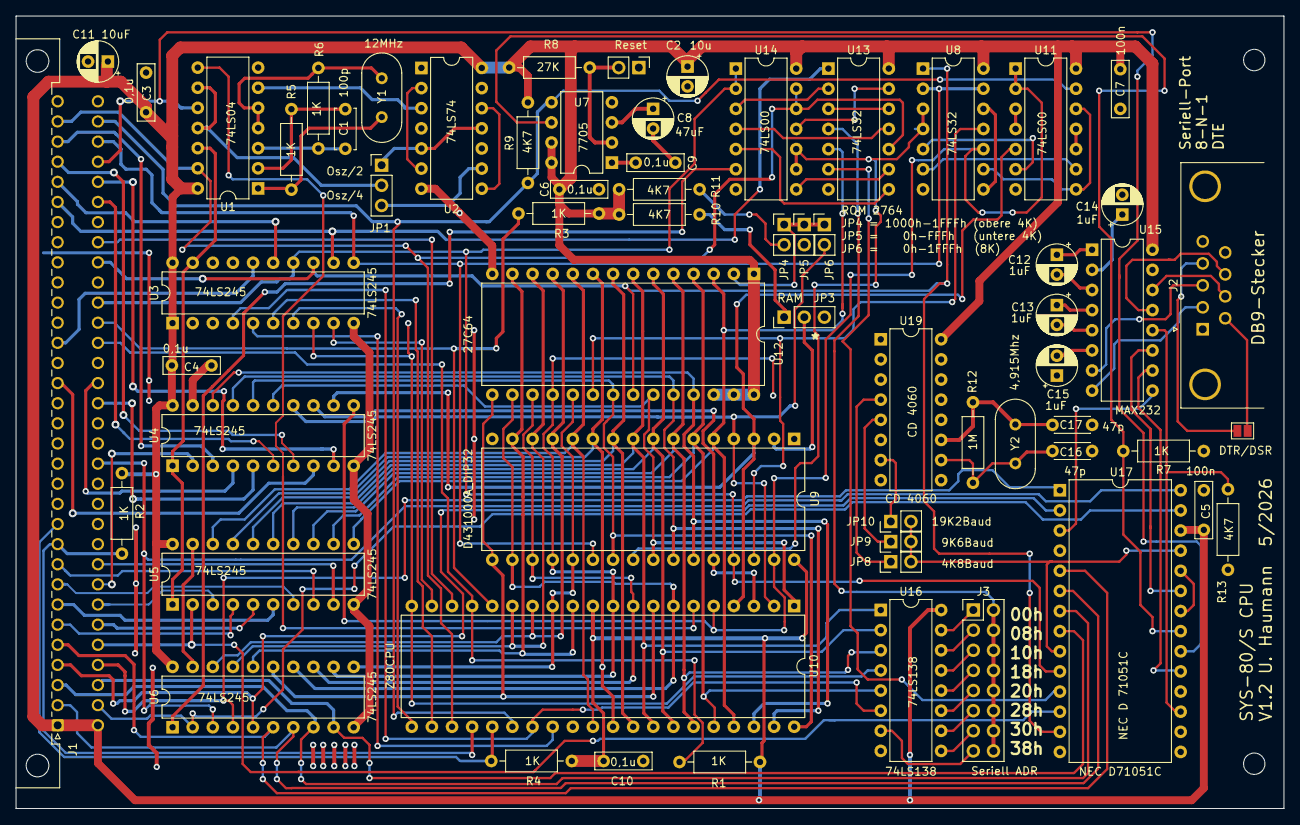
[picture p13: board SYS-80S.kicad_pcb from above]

Board: 2 copper layers, 160.0 x 100.0 mm, 65 parts (0 on the bottom side), 138 nets.

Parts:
C1: 100p; C_Disc_D5.0mm_W2.5mm_P5.00mm
C2, C11: 10uF; CP_Radial_D5.0mm_P2.50mm
C3, C4, C5, C6, C7, C9, C10: 100n; C_Rect_L7.0mm_W2.0mm_P5.00mm
C8: 47uF; CP_Radial_D5.0mm_P2.50mm
C12, C13, C14, C15: 1uF; CP_Radial_D5.0mm_P2.50mm
C16, C17: 47p; C_Disc_D4.3mm_W1.9mm_P5.00mm
H1, H2: 2,5; MountingHole_2.7mm_M2.5_ISO7380
J1: C64AC; DIN41612_C_2x32_Male_Horizontal_THT
J2: DB9_Male; DSUB-9_Male_Horizontal_P2.77x2.84mm_EdgePinOffset4.94mm_Hou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
J3: ADR-SEL; PinHeader_2x08_P2.54mm_Vertical
JP1, JP3: Jumper_3_Open; PinHeader_1x03_P2.54mm_Vertical
JP2: Reset; PinHeader_1x02_P2.54mm_Vertical
JP4, JP5, JP6, JP8, JP9, JP10: .; PinHeader_1x02_P2.54mm_Vertical
JP7: DTR/DSR; SolderJumper-2_P1.3mm_Open_Pad1.0x1.5mm
R1, R2, R3, R4, R5, R6, R7: 1K; R_Axial_DIN0207_L6.3mm_D2.5mm_P10.16mm_Horizontal
R8: 27K; R_Axial_DIN0207_L6.3mm_D2.5mm_P10.16mm_Horizontal
R9, R10, R11, R13: 4K7; R_Axial_DIN0207_L6.3mm_D2.5mm_P10.16mm_Horizontal
R12: 1M; R_Axial_DIN0207_L6.3mm_D2.5mm_P10.16mm_Horizontal
U1: 74LS04; DIP-14_W7.62mm
U2: 74LS74; DIP-14_W7.62mm
U3, U4, U5, U6: 74LS245; DIP-20_W7.62mm
U7: TL7705A; DIP-8_W7.62mm
U8, U13: 74LS32; DIP-14_W7.62mm
U9: D431000A_DIP32; DIP-32_W15.24mm
U10: Z80CPU; DIP-40_W15.24mm
U11, U14: 74LS00; DIP-14_W7.62mm
U12: 27C64; DIP-28_W15.24mm
U15: MAX232; DIP-16_W7.62mm
U16: 74LS138; DIP-16_W7.62mm
U17: NEC D71051C; DIP-28_W15.24mm
U19: CD 4060; DIP-16_W7.62mm
Y1: 16MHz; Crystal_HC18-U_Vertical
Y2: 4,915Mhz; Crystal_HC18-U_Vertical

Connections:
+5V: C2.1, C3.2, C4.2, C5.2, C6.2, C7.2, C10.2, C11.1, J1.A1, J1.C1, R1.1, R2.1, R3.1, R4.1, R8.2, R9.1, R10.2, R11.2, U1.14, U2.14, U3.1, U3.20, U4.20, U5.20, U6.20, U7.7, U7.8, U8.14, U9.32, U10.11, U11.14, U12.1, U12.26, U12.27, U12.28, U13.14, U14.14, U15.16, U16.16, U17.26, U19.16
+RESET: R7.2, U7.6, U17.21
-BUSAK: J1.A31, U1.13, U10.23, U13.10, U14.12, U14.13
-BUSRQ: J1.A11, R4.2, U10.25
-CS-RAM: U8.3, U8.4, U9.24, U14.9, U14.10
-CS-ROM: U8.11, U9.30, U12.20
-HALT: J1.C25, U10.18
-INT: J1.C21, R3.2, U10.16
-IORQv: J1.A27, U3.12, U13.1
-M1v: J1.A20, U3.16
-MREQv: J1.C30, U3.11, U8.2, U8.13, U9.22
-NMI: J1.C20, R1.2, U10.17
-RDv: J1.C24, U3.13, U8.1, U12.22, U17.13
-RESET: J1.C31, R9.2, U7.5, U10.26, U11.13
-RFSHv: J1.A28, U3.15
-WAIT: J1.A10, R2.2, U10.24
-WRv: J1.C22, U3.14, U9.29, U14.1, U14.2, U17.10
A0: U5.18, U9.12, U10.30, U12.10
A0v: J1.C5, U5.2, U17.12
A1: U5.17, U9.11, U10.31, U12.9
A1v: J1.C7, U5.3
A2: U5.16, U9.10, U10.32, U12.8
A2v: J1.A6, U5.4
A3: U5.15, U9.9, U10.33, U12.7, U16.1
A3v: J1.C6, U5.5
A4: U5.14, U9.8, U10.34, U12.6, U16.2
A4v: J1.A7, U5.6
A5: U5.13, U9.7, U10.35, U12.5, U16.3
A5v: J1.A8, U5.7
A6: U5.12, U9.6, U10.36, U12.4, U16.5
A6v: J1.A9, U5.8
A7: U5.11, U9.5, U10.37, U12.3, U13.5
A7v: J1.C9, U5.9
A8: U4.18, U9.27, U10.38, U12.25
A8v: J1.C8, U4.2
A9: U4.17, U9.26, U10.39, U12.24
A9v: J1.A30, U4.3
A10: U4.16, U9.23, U10.40, U12.21
A10v: J1.C18, U4.4
A11: U4.15, U9.25, U10.1, U12.23
A11v: J1.C17, U4.5
A12: JP6.2, U4.14, U9.4, U10.2
A12v: J1.C27, U4.6
A13: U4.13, U9.28, U10.3
A13v: J1.A29, U4.7
A14: U4.12, U9.3, U10.4, U11.5
A14v: J1.A18, U4.8
A15: U4.11, U8.10, U9.31, U10.5, U11.1, U11.2
A15v: J1.C28, U4.9
BAUD: JP8.2, JP9.2, JP10.2, U17.9, U17.25
BUSAK: U1.12, U3.19, U4.1, U5.1
CLK: U1.8, U10.6
CTS: R13.1, U15.12, U17.17
D0: U6.18, U9.13, U10.14, U12.11
D0v: J1.C2, U6.2, U17.27
D1: U6.17, U9.14, U10.15, U12.12
D1v: J1.C14, U6.3, U17.28
D2: U6.16, U9.15, U10.12, U12.13
D2v: J1.C4, U6.4, U17.1
D3: U6.15, U9.17, U10.8, U12.15
D3v: J1.A4, U6.5, U17.2
D4: U6.14, U9.18, U10.7, U12.16
D4v: J1.A5, U6.6, U17.5
D5: U6.13, U9.19, U10.9, U12.17
D5v: J1.A2, U6.7, U17.6
D6: U6.12, U9.20, U10.10, U12.18
D6v: J1.A3, U6.8, U17.7
D7: U6.11, U9.21, U10.13, U12.19
D7v: J1.C3, U6.9, U17.8
GND: C2.2, C3.1, C4.1, C5.1, C6.1, C7.1, C8.2, C9.1, C10.1, C11.2, C14.2, C15.1, C16.1, C17.1, J1.A32, J1.C32, J2.5, JP2.1, JP3.3, JP5.2, R7.1, R13.2, U1.7, U2.7, U3.10, U4.10, U4.19, U5.10, U5.19, U6.10, U6.19, U7.4, U8.7, U9.16, U10.29, U11.7, U12.14, U13.7, U14.7, U15.15, U16.8, U17.4, U19.8, U19.12
IO-Data: U6.1, U14.6
IORQ*: U3.8, U10.20, U16.4
M1*: U3.4, U10.27, U16.6
MREQ*: U3.9, U10.19
unnamed: C1.1, R6.2, U1.3
unnamed: C1.2, R5.1, U1.2
unnamed: C8.1, U7.3
unnamed: C9.2, U7.1
unnamed: C12.1, U15.1
unnamed: C12.2, U15.3
unnamed: C13.1, U15.4
unnamed: C13.2, U15.5
unnamed: C14.1, U15.2
unnamed: C15.2, U15.6
unnamed: C16.2, R12.1, U19.10, Y2.1
unnamed: C17.2, R12.2, U19.11, Y2.2
unnamed: J2.2, U15.8
unnamed: J2.3, U15.7
unnamed: J2.4, JP7.2
unnamed: J2.6, JP7.1
unnamed: J2.7, U15.14
unnamed: J2.8, U15.13
unnamed: J3.1, U16.15
unnamed: J3.3, U16.14
unnamed: J3.5, U16.13
unnamed: J3.7, U16.12
unnamed: J3.9, U16.11
unnamed: J3.2, J3.4, J3.6, J3.8, J3.10, J3.12, J3.14, J3.16, U13.4
unnamed: J3.11, U16.10
unnamed: J3.13, U16.9
unnamed: J3.15, U16.7
unnamed: JP1.1, U2.5, U2.11
unnamed: JP1.2, U1.9, U1.11
unnamed: JP1.3, U2.9
unnamed: JP2.2, R8.1, U7.2
unnamed: JP3.1, R10.1
unnamed: JP3.2, U9.2
unnamed: JP4.1, JP5.1, JP6.1, U12.2
unnamed: JP4.2, R11.1
unnamed: JP8.1, U19.4
unnamed: JP9.1, U19.5
unnamed: JP10.1, U19.7
unnamed: R5.2, U1.1, Y1.1
unnamed: R6.1, U1.4, U1.5, Y1.2
unnamed: U1.6, U2.3
unnamed: U2.2, U2.6
unnamed: U2.8, U2.12
unnamed: U8.8, U8.12
unnamed: U11.3, U11.4
unnamed: U8.5, U11.6
unnamed: U8.6, U11.9
unnamed: U11.10, U11.11
unnamed: U8.9, U11.8, U11.12
unnamed: U13.2, U14.3
unnamed: U13.8, U14.5
unnamed: U13.9, U14.8
unnamed: U13.11, U14.4
unnamed: U13.3, U13.12
unnamed: U13.13, U14.11
unnamed: U17.22, U17.24
PHI: J1.C29, U1.10, U17.20
RD*: U3.7, U10.21
RFSH*: U3.5, U10.28
RTS: U15.11, U17.23
RXD: U15.9, U17.3
TXD: U15.10, U17.19
UART-CS: U13.6, U17.11
WR*: U3.6, U10.22

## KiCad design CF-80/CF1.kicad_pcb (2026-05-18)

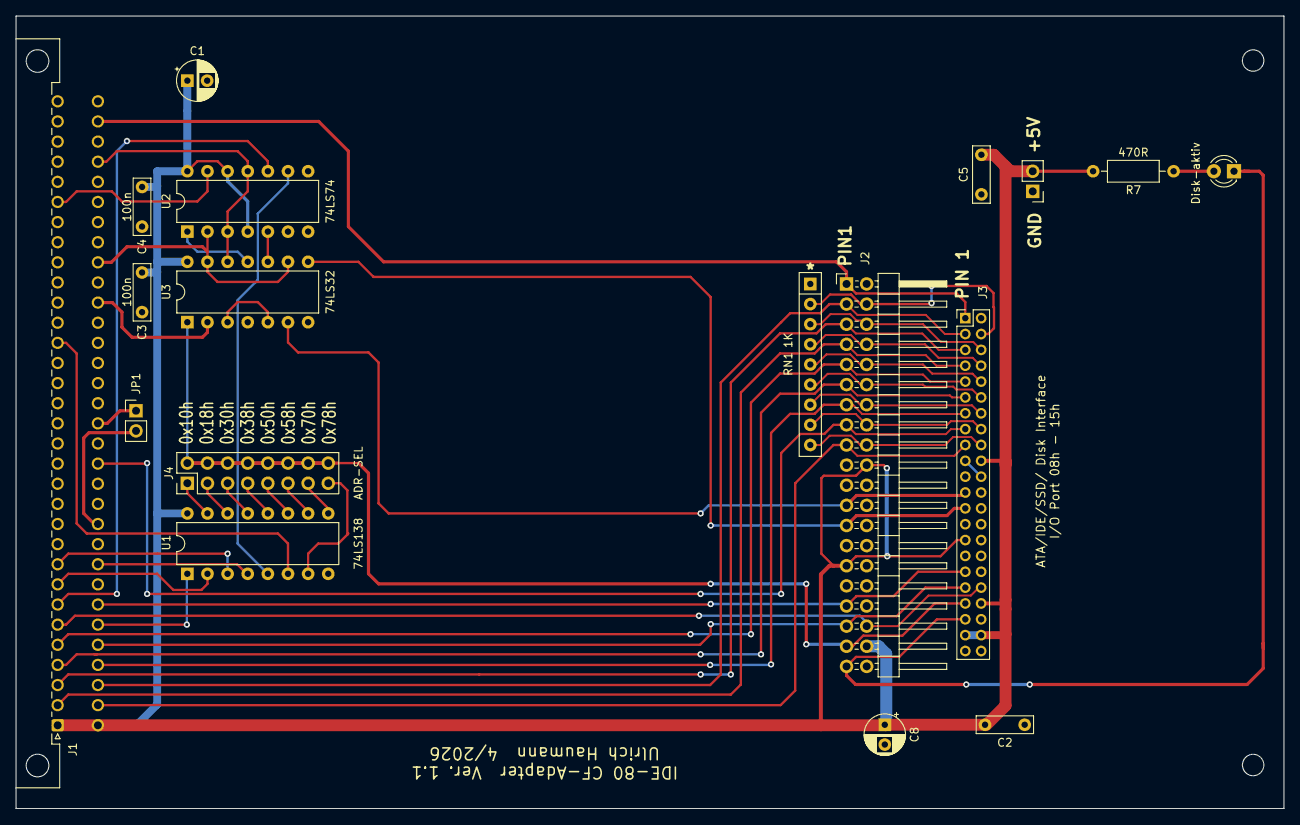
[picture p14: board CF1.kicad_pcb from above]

Board: 2 copper layers, 160.0 x 100.0 mm, 20 parts (0 on the bottom side), 51 nets.

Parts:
C1, C8: 10uF; CP_Radial_D5.0mm_P2.50mm
C2, C3, C4, C5: 100n; C_Rect_L7.0mm_W2.0mm_P5.00mm
D2: Disk-aktiv; LED_D3.0mm
H1, H2: MountingHole; MountingHole_2.7mm_M2.5
J1: C64AC; DIN41612_C_2x32_Male_Horizontal_THT
J2: IDE-40; PinHeader_2x20_P2.54mm_Horizontal
J3: IDE-44; PinHeader_2x22_P2.00mm_Vertical
J4: ADR-SEL; PinHeader_2x08_P2.54mm_Vertical
JP1, JP4: .; PinHeader_1x02_P2.54mm_Vertical
R7: 470R; R_Axial_DIN0207_L6.3mm_D2.5mm_P10.16mm_Horizontal
RN1: 1K; R_Array_SIP9
U1: 74LS138; DIP-16_W7.62mm
U2: 74LS74; DIP-14_W7.62mm
U3: 74LS32; DIP-14_W7.62mm

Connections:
+5V: C1.1, C2.2, C3.2, C4.2, C5.2, C8.1, J1.A1, J1.C1, J2.20, J2.29, J2.38, J3.20, J3.29, J3.38, J3.41, J3.42, JP4.2, R7.2, U1.16, U2.4, U2.12, U2.14, U3.14
-CS1-DSK: J2.37, J3.37, J4.2, J4.4, J4.6, J4.8, J4.10, J4.12, J4.14, J4.16, U3.1
-IORQv: J1.A27, U2.13
-M1v: J1.A20, U1.6
-RDv: J1.C24, U2.2, U3.9, U3.13
-RESET: J1.C31, J2.1, J3.1
-WRv: J1.C22, U3.2
A0v: J1.C5, J2.35, J3.35
A1v: J1.C7, J2.33, J3.33
A2v: J1.A6, J2.36, J3.36
A3v: J1.C6, U1.1
A4v: J1.A7, U2.10
A5v: J1.A8, U1.2
A6v: J1.A9, U1.3
A7v: J1.C9, U1.4
CLK: J1.C29, U2.3, U2.11, U3.12
D0v: J1.C2, J2.17, J3.17
D1v: J1.C14, J2.15, J3.15
D2v: J1.C4, J2.13, J3.13
D3v: J1.A4, J2.11, J3.11
D4v: J1.A5, J2.9, J3.9
D5v: J1.A2, J2.7, J3.7
D6v: J1.A3, J2.5, J3.5
D7v: J1.C3, J2.3, J3.3
GND: C1.2, C2.1, C3.1, C4.1, C5.1, C8.2, J1.A32, J1.C32, J2.2, J2.19, J2.22, J2.24, J2.26, J2.30, J2.40, J3.2, J3.19, J3.22, J3.24, J3.26, J3.30, J3.40, J3.43, JP4.1, RN1.1, U1.8, U2.7, U3.4, U3.7
IEI: J1.C11, JP1.2
IEO: J1.C16, JP1.1
IORD*: J2.25, J3.25, U3.8
IOWR*: J2.23, J3.23, U3.6
unnamed: D2.1, J2.39, J3.39
unnamed: D2.2, R7.1
unnamed: J4.1, U1.15
unnamed: J4.3, U1.14
unnamed: J4.5, U1.13
unnamed: J4.7, U1.12
unnamed: J4.9, U1.11
unnamed: J4.11, U1.10
unnamed: J4.13, U1.9
unnamed: J4.15, U1.7
unnamed: U1.5, U2.9
unnamed: U2.1, U3.11
unnamed: U2.5, U3.10
unnamed: U3.3, U3.5
RGND1: J2.4, J3.4, RN1.2
RGND2: J2.6, J3.6, RN1.3
RGND3: J2.8, J3.8, RN1.4
RGND4: J2.10, J3.10, RN1.5
RGND5: J2.12, J3.12, RN1.6
RGND6: J2.14, J3.14, RN1.7
RGND7: J2.16, J3.16, RN1.8
RGND8: J2.18, J3.18, RN1.9

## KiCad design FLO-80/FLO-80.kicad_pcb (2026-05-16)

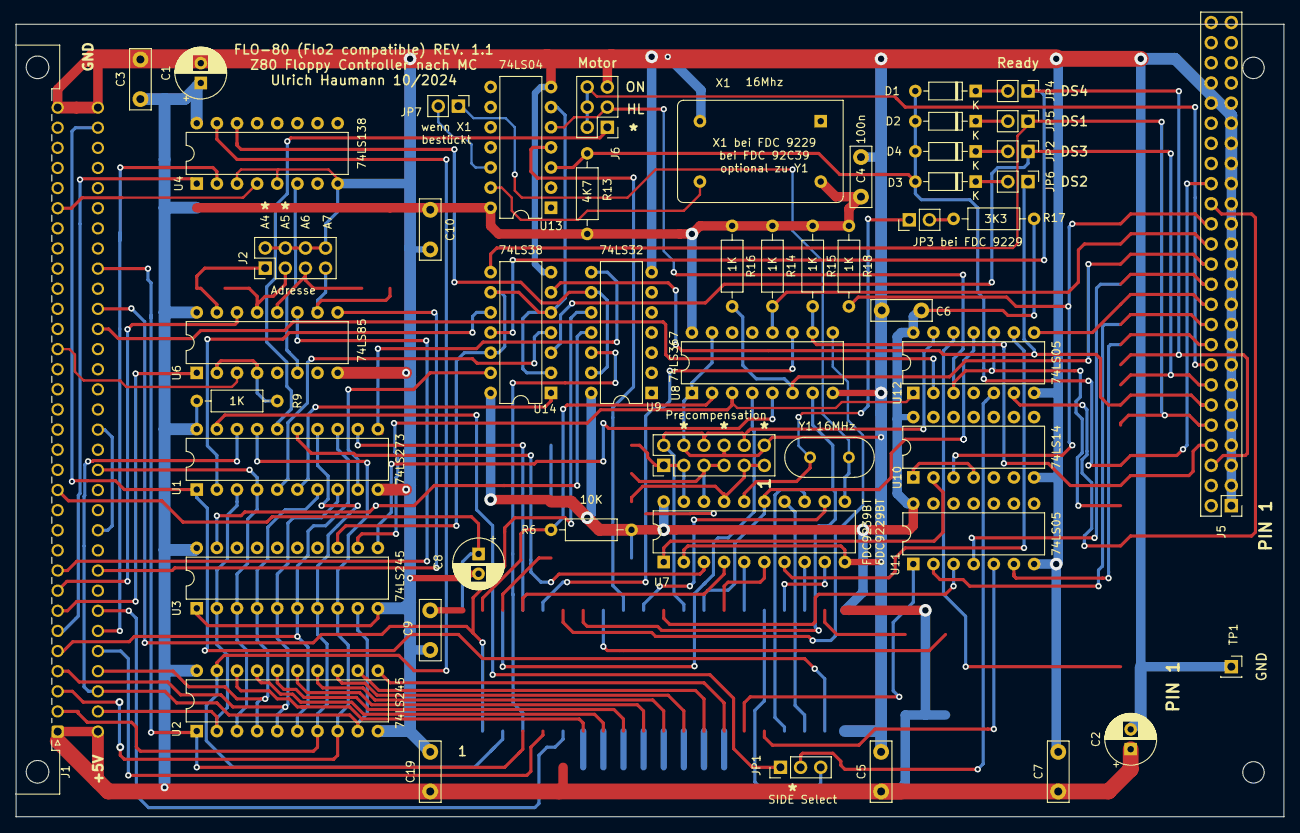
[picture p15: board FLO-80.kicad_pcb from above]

Board: 2 copper layers, 160.0 x 100.0 mm, 53 parts (0 on the bottom side), 81 nets.

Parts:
C1, C2, C8: 10u; CP_Radial_D6.3mm_P2.50mm
C3, C4, C5, C6, C7, C9, C10, C19: 100n; C_Disc_D7.5mm_W2.5mm_P5.00mm
D1, D2, D3, D4: 1N4148; D_DO-35_SOD27_P7.62mm_Horizontal
H1, H2: 2,7; MountingHole_2.7mm
J1: C64AC; DIN41612_C_2x32_Male_Horizontal_THT
J2: Adresse; PinHeader_2x04_P2.54mm_Vertical
J3: Precomp; PinHeader_2x06_P2.54mm_Vertical
J5: 5,25; PinHeader_2x17_P2.54mm_Vertical
J6: Motor ON; PinHeader_2x03_P2.54mm_Vertical
JP1: Side; PinHeader_1x03_P2.54mm_Vertical
JP2, JP3, JP4, JP5, JP6, JP7: Jumper; PinHeader_1x02_P2.54mm_Vertical
R6: 10K; R_Axial_DIN0207_L6.3mm_D2.5mm_P10.16mm_Horizontal
R9, R14, R15, R16, R18: 1K; R_Axial_DIN0207_L6.3mm_D2.5mm_P10.16mm_Horizontal
R13: 4K7; R_Axial_DIN0207_L6.3mm_D2.5mm_P10.16mm_Horizontal
R17: 3K3; R_Axial_DIN0207_L6.3mm_D2.5mm_P10.16mm_Horizontal
TP1: TestPoint; PinSocket_1x01_P2.54mm_Vertical
U1: 74LS273; DIP-20_W7.62mm
U2, U3: 74LS245; DIP-20_W7.62mm
U4: 74LS138; DIP-16_W7.62mm
U6: 74LS85; DIP-16_W7.62mm
U7: FDC9239BT; DIP-20_W7.62mm
U8: 74LS367; DIP-16_W7.62mm
U9: 74LS32; DIP-14_W7.62mm
U10: 74LS14; DIP-14_W7.62mm
U11, U12: 74LS05; DIP-14_W7.62mm
U13: 74LS04; DIP-14_W7.62mm
U14: 74LS38; DIP-14_W7.62mm
X1: 16Mhz; Oscillator_DIP-14
Y1: 16MHz; Crystal_HC18-U_Vertical

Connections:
+5V: C1.1, C2.1, C3.1, C4.1, C5.1, C6.1, C7.1, C10.1, C19.1, J1.A1, J1.C1, R6.1, R9.1, R13.1, R14.1, R15.1, R16.1, R17.1, R18.1, U1.20, U2.20, U3.20, U4.16, U6.16, U7.20, U8.16, U9.14, U10.14, U11.14, U12.14, U13.14, U14.14, X1.14
+12V: C8.1, C9.1, J1.A13
A2: J1.A6, U4.1
A3: J1.C6, U4.2
A4: J1.A7, U6.1
A5: J1.A8, U6.14
A6: J1.A9, U6.11
A7: J1.C9, U6.9
CS_U3: U4.14, U9.9, U9.13
D0: J1.C2, U1.3, U2.2, U3.2
D1: J1.C14, U1.4, U2.3, U3.3
D2: J1.C4, U1.7, U2.4, U3.4
D3: J1.A4, U1.8, U2.5, U3.5
D4: J1.A5, U1.13, U2.6, U3.6
D5: J1.A2, U1.14, U2.7, U3.7
D6: J1.A3, U1.17, U2.8, U3.8
D7: J1.C3, U1.18, U2.9, U3.9
DIRC: J5.34, U11.6
DS1: J5.26, JP5.1, U14.8
DS2: J5.28, JP6.1, U14.6
DS3: J5.30, JP2.1, U14.3
DS4: J5.32, JP4.1, U14.11
GND: C1.2, C2.2, C3.2, C4.2, C5.2, C6.2, C7.2, C8.2, C9.2, C10.2, C19.2, J1.A32, J1.C32, J2.2, J2.4, J2.6, J2.8, J3.4, J3.8, J3.12, J5.1, J5.3, J5.5, J5.7, J5.9, J5.11, J5.13, J5.15, J5.17, J5.19, J5.21, J5.23, J5.25, J5.27, J5.29, J5.31, J5.33, J5.35, J5.37, J5.39, J5.41, J5.43, J5.45, J5.47, J5.49, J6.5, TP1.1, U1.10, U2.10, U3.1, U3.10, U4.3, U4.5, U4.8, U6.8, U7.2, U7.10, U8.1, U8.8, U8.15, U9.7, U10.7, U11.7, U12.7, U13.7, U14.7, X1.7
HEADLOAD: J5.18, J6.3, U12.3, U12.10, U13.5
HLD_F: U7.15, U12.11
INDEX: J5.20, R15.2, U8.10
L-0: U1.2, U14.10
L-1: U1.5, U14.4
L-2: U1.6, U14.1
L-3: U1.9, U14.13
L-6: J6.1, U1.16
L-7: JP1.1, U1.19
MOTORON: J6.2, J6.4, J6.6
unnamed: D1.1, JP4.2
unnamed: D2.1, JP5.2
unnamed: D3.1, JP6.2
unnamed: D4.1, JP2.2
unnamed: J1.C11, J1.C16
unnamed: J2.1, U6.15
unnamed: J2.3, U6.13
unnamed: J2.5, U6.12
unnamed: J2.7, U6.10
unnamed: J3.1, J3.3, U7.19
unnamed: J3.5, J3.7, U7.18
unnamed: J3.9, J3.11, U7.17
unnamed: JP1.2, U12.5
unnamed: JP3.1, U7.16, Y1.2
unnamed: JP3.2, R17.2
unnamed: JP7.1, U7.11, Y1.1
unnamed: JP7.2, U13.12
unnamed: R6.2, U8.2
unnamed: R9.2, U6.2, U6.4
unnamed: U1.11, U9.8
unnamed: U1.12, U7.4
unnamed: U1.15, U7.3
unnamed: U2.19, U4.15
unnamed: U3.11, U8.5
unnamed: U3.19, U9.11
unnamed: U4.6, U6.6
unnamed: U10.1, U10.4
unnamed: U3.12, U8.3, U12.1
unnamed: U3.13, U13.6, U14.2, U14.5, U14.9, U14.12
unnamed: U13.13, X1.8
RAWIN: U7.1, U10.2
RAWRQ: J5.46, R18.2, U10.3
READY: D1.2, D2.2, D3.2, D4.2, J5.22, R13.2, U13.3
SIDE: J5.14, U12.6
STEP: J5.36, U11.2
TG43: J5.2, U12.12
TG43-F: J3.2, J3.6, J3.10, U12.13
TK0: J5.42, R16.2, U8.6
WDATA: J5.38, U12.8
WDOUT: U7.7, U12.9
WG: J5.40, U11.4
WRTPT: J5.44, R14.2, U8.12
~INT: J1.C21, U12.2
~IOREQ: J1.A27, U4.4
~M1: J1.A20, U6.3
~RD: J1.C24, U2.1, U9.12
~RESET: J1.C31, U1.1
~WR: J1.C22, U9.10

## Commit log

2026-05-19 Backplanes, Floppyadapter
    8er und 5er Backplane
    3,5" Floppyadapter
    [BUS-80-5-B_Mask.gbs, BUS-80-5-B_Silkscreen.gbo, BUS-80-5-Component.gtl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]
2026-05-19 BUS-80-8 Schaltplan und Foto
2026-07-04 BIOS31 und Mon80V2
    Dokumentierungsfortschritte
